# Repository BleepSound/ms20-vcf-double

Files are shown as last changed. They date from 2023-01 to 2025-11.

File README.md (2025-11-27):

[][cc-by-sa]

# Double MS20-VCF

Latest documentation available at https://bleepsound.github.io/modules/

This work is licensed under a
[Creative Commons Attribution-ShareAlike 4.0 International License][cc-by-sa].

[][cc-by-sa]

[cc-by-sa]: http://creativecommons.org/licenses/by-sa/4.0/
[cc-by-sa-image]: https://licensebuttons.net/l/by-sa/4.0/88x31.png
[cc-by-sa-shield]: https://img.shields.io/badge/License-CC%20BY--SA%204.0-lightgrey.svg

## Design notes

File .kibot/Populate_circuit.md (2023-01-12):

# Populate Manual for MS20-VCF-Double-circuitboard

Follow this manual to populate the PCB: 

The basic rule is, always go from the smallest to the highest component on the board !

- [[front | ]] This is the front side of the board we are populating
- [[back | ]] This is the back side of the board we are populating, and we are gonna start by this side.
- [[back | U1, U3 ]] Start by the SMD components, here U1 and U3, the LM13700s. 
- [[back | FB2, FB1]] After the smd components, do the beads.
- [[back | C7, C8, C11, C12 ]] Do all the ceramic capacitors
- [[back | C1, C5, C10, C15 ]] Finish the capacitors with the electrolytic ones, watch out for their orientation, they are polarized.
- [[back | J8, ResLv1, ResVol1, ResLv2, ResVol2 ]] Finish the back by putting the trimmers and the power connector.

The back is done, we can flip the PCB and start the front !

- [[front | ]]
- [[front | D1, D2, D3, D4, D5, D6, D8, D9, D10, D11, D12, D13 ]] First, populate all the diodes.
- [[front | R1, R2, R5, R6, R17, R23, R24, R27, R28, R39, R3, R4, R10, R11, R25, R26, R32, R33, R13, R14, R18, R35, R36, R40, R7, R9, R29, R31, R15, R37 ]] You then can do all the resistors (by value so you don't make mistakes)
- [[front | Q1, Q2, Q3, Q4 ]] You then can add the transitors, watch out for their orientation.
- [[front | U2, U4 ]] Add the socket for the TL072, making sure you get the orientation right. Don't add the Tl072 yet, you'll add it at the end. 
- [[front | C2, C3, C4, C16, C17, C18, C6, C9, C13, C14]] Add the capacitors

## Conclusion

This is the end of the build, if yoy have any questions, don't hesitate !

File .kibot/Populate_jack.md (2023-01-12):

# Populate Manual for MS20-VCF-Double-jackboard

Follow this manual to populate the PCB: 

The basic rule is, always go from the smallest to the highest component on the board !

- [[front | ]] This is the front side of the board we are populating (we'll start there)
- [[back | ]] This is the back side of the board we are populating (not much there on this build)
- [[front | R8, R12, R30, R34, R16, R38, R19, R41, R20, R42, R21, R43, R22 ]] We'll do all the resistors first (by value so you don't make mistakes)

We'll switch to the back:

- [[back | J4, J7, J10, J14 ]] just one type of components, the connectors to the circuit board. Use **Female** connectors on this side.

The last step  concern the jacks, potentiometers and switches and front panel LEDs. Basically, anything that is accessible throught the front panel. You first place them.

:warning: DO NOT SOLDER THEM YET :warning:

(this is really important !!)

- [[front | CUTCV1, CUTCV2, CUTOFF1, CUTOFF2, Res1, Res2, SW1, SW3, SW2, J1, J2, J5, J11, J12, J15, D7]] Do Not Solder Them! place them first and put the front panel in place. *For the pot **CUTCV1, CUTCV2**, use the small 100k pot (not D shaped)* The other pots are for CUTOFF1 and 2 and Res1 and 2. You'll be able to put the knobs of your choice on those. You can place the led too (D7). You'll have to place it as close as possible to the "window" on the front panel.

You then put in place the front panel, making sure everything fits. Once all the jack sockets and switches are fastenned to the front panel, you can solder them, and only then !!!

## Conclusion

This is the end of the build, if yoy have any questions, don't hesitate !

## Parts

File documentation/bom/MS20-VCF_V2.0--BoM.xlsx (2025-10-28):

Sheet: BoM
MS20-VCF_V2.0 Bill of Materials
Schematic: | MS20-VCF | Component Groups: | 23
Variant: | default | Component Count: | 109 (2 SMD/ 107 THT)
Revision: | 2.0 | Fitted Components: | 109 (2 SMD/ 107 THT)
Date: | 2025-10-19 | Number of PCBs: | 1
KiCad Version: | 9.0.4-9.0.4-0~ubuntu22.04.1 | Total Components: | 109
Row | Description | References | Value | Quantity Per PCB | Links | Comments
1 | Multilayer Monolithic Ceramic capacitor 50V 10% | C2 C3 C4 C16 C17 C18 | 1nF | 6 | https://www.taydaelectronics.com/capacitors/monolithic-ceramic-capacitor.html
2 | Multilayer Monolithic Ceramic capacitor 50V 10% | C6 C7 C8 C9 C11 C12 C13 C14 | 100nF | 8 | https://www.taydaelectronics.com/capacitors/monolithic-ceramic-capacitor.html
3 | 10uF Electrolytic capacitor, 2.0mm pitch, 5mm diameter | C1 C5 C10 C15 | 10uF | 4 | https://www.taydaelectronics.com/capacitors/electrolytic-capacitors.html
4 | Alpha/bourns vertical potentiometer | CUTCV1 CUTCV2 CUTOFF1 CUTOFF2 Res1 Res2 | B100k | 6 | https://www.thonk.co.uk/shop/alpha-9mm-pots/ | Use trimmer style pots for CUTCV1 and 2
5 | Switching Signal Diode 200mA 100V DO-35 | D1 D2 D3 D4 D5 D6 D8 D9 D10 D11 D12 D13 | 1N4148 | 12 | https://www.taydaelectronics.com/1n4148-switching-signal-diode.html
6 | 40V 1A Schottky Barrier Rectifier Diode, DO-41 | D7 D14 | 1N5819 (http://www.vishay.com/docs/88525/1n5817.pdf) | 2 | https://www.taydaelectronics.com/1n5819-schottky-barrier-diode-1a-40v.html
7 | 2.54mm pitch pin socket vertical 1x6pos | J3 J6 J9 J13 | Conn_CircuitBoard | 4
8 | 2.54mm pitch pin header vertical 1x6pos | J4 J7 J10 J14 | Conn_JackBoard | 4
9 | Eurorack 10 pin shrouded power header IDC | J8 | Power Input | 1 | https://www.thonk.co.uk/shop/eurorack-diy-essentials/
10 | Thonkiconn jack | J1 J2 J5 J11 J12 J15 | jack | 6 | https://www.thonk.co.uk/shop/thonkiconn/
11 | BC559 PNP General Purpose Transistor | Q1 Q2 Q3 Q4 | BC559 (https://www.onsemi.com/pub/Collateral/BC556BTA-D.pdf) | 4 | https://www.taydaelectronics.com/bc558-bc558b-transistor-pnp-0-1a-30v.html | Substitute BC558
12 | 2.5mm*6.8mm 1/4W 1% Metal film resistor | R3 R4 R10 R11 R25 R26 R32 R33 | 470 | 8 | https://www.taydaelectronics.com/resistors/1-4w-metal-film-resistors/test-group-2.html
13 | 2.5mm*6.8mm 1/4W 1% Metal film resistor | R8 R12 R15 R30 R34 R37 | 1k | 6 | https://www.taydaelectronics.com/resistors/1-4w-metal-film-resistors/test-group-2.html
14 | 2.5mm*6.8mm 1/4W 1% Metal film resistor | R7 R9 R29 R31 | 1.8k | 4 | https://www.taydaelectronics.com/resistors/1-4w-metal-film-resistors/test-group-2.html
15 | 2.5mm*6.8mm 1/4W 1% Metal film resistor | R13 R14 R18 R35 R36 R40 | 2.2k | 6 | https://www.taydaelectronics.com/resistors/1-4w-metal-film-resistors/test-group-2.html
16 | 2.5mm*6.8mm 1/4W 1% Metal film resistor | R19 R41 | 33k | 2 | https://www.taydaelectronics.com/resistors/1-4w-metal-film-resistors/test-group-2.html
17 | 2.5mm*6.8mm 1/4W 1% Metal film resistor | R21 R43 | 56k | 2 | https://www.taydaelectronics.com/resistors/1-4w-metal-film-resistors/test-group-2.html
18 | 2.5mm*6.8mm 1/4W 1% Metal film resistor | R16 R38 | 82k | 2 | https://www.taydaelectronics.com/resistors/1-4w-metal-film-resistors/test-group-2.html
19 | 2.5mm*6.8mm 1/4W 1% Metal film resistor | R1 R2 R5 R6 R17 R20 R23 R24 R27 R28 R39 R42 | 100k | 12 | https://www.taydaelectronics.com/resistors/1-4w-metal-film-resistors/test-group-2.html
20 | Trimmer potentiometer, 25 turn series 3296W | ResLv1 ResLv2 ResVol1 ResVol2 | 10k (https://www.taydaelectronics.com/potentiometer-variable-resistors/cermet-potentiometers/3296w/10k-ohm-trimmer-potentiometer-cermet-25-turns-3296w.html) | 4 | https://www.thonk.co.uk/shop/25-turn-trimmer-potentiometer/ | Use multi turn Cermet style 3296 pots
21 | Mini Toggle Switch DPDT On-On | SW1 SW3 | Hpass/Lpass Switch (https://www.taydaelectronics.com/mini-toggle-switch-1m-series-dpdt-on-on.html) | 2 | https://www.taydaelectronics.com/mini-toggle-switch-dpdt-on-on.html | DPDT Switch, On-Off-On
22 | Dual Transconductance Amplifiers | U1 U3 | LM13700 (http://www.ti.com/lit/ds/symlink/lm13700.pdf) | 2 | https://eu.mouser.com/c/semiconductors/amplifier-ics/transconductance-amplifiers/?series=LM13700
23 | Operational Amplifiers - Op Amps Dual JFET In Low N | U2 U4 | TL072 (http://www.ti.com/lit/ds/symlink/tl071.pdf) | 2 | https://eu.mouser.com/ProductDetail/Texas-Instruments/TL072IP?qs=5BZzbFV4k2v7IBrcArRPQw%3D%3D

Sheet: Colors
Columns colors
KiCad Fields (default)
Generated Fields
User Fields
Empty Fields

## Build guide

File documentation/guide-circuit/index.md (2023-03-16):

# Populate Manual for MS20-VCF-Double-circuitboard

Follow this manual to populate the PCB:

The basic rule is, always go from the smallest to the highest component on the board !

####  This is the front side of the board we are populating

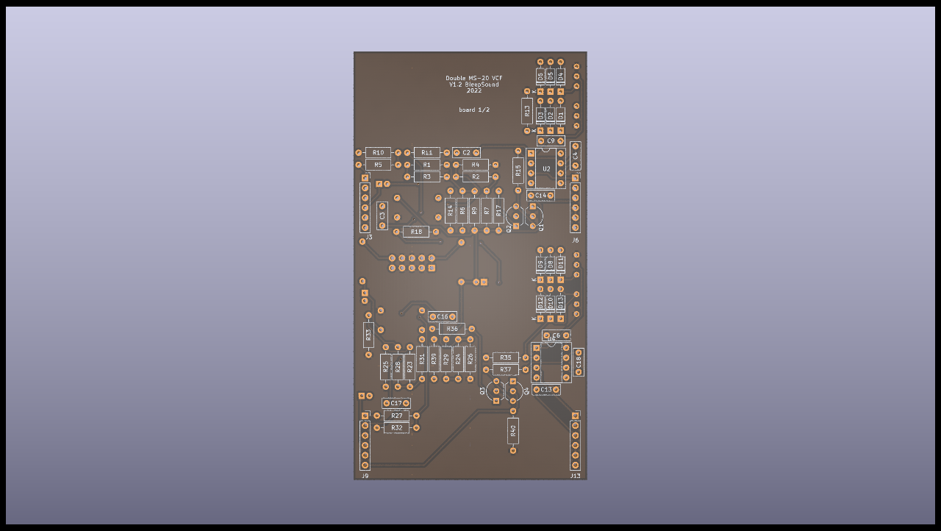
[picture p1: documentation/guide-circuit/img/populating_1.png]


####  This is the back side of the board we are populating, and we are gonna start by this side.

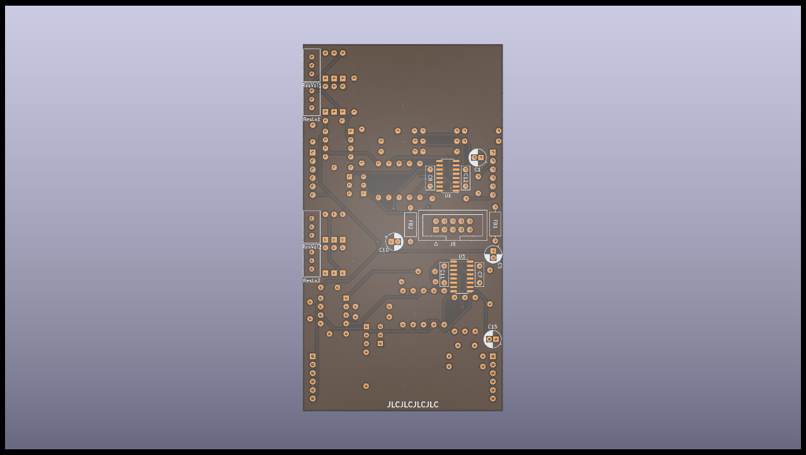
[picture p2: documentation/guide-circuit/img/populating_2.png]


####  Start by the SMD components, here U1 and U3, the LM13700s.

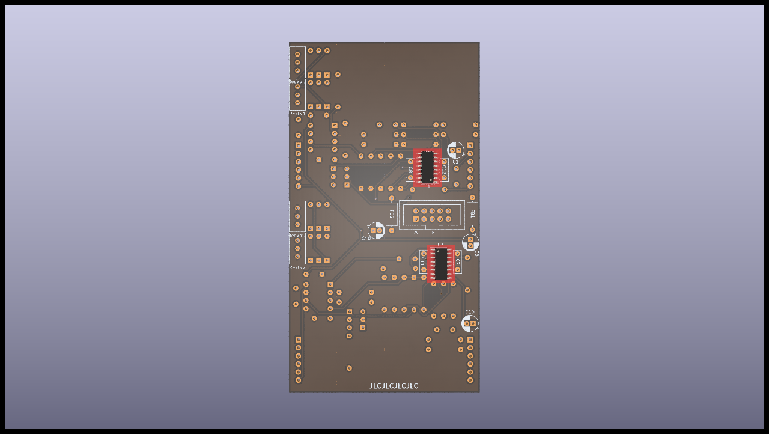
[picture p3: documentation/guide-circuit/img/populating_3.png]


####  After the smd components, do the beads.

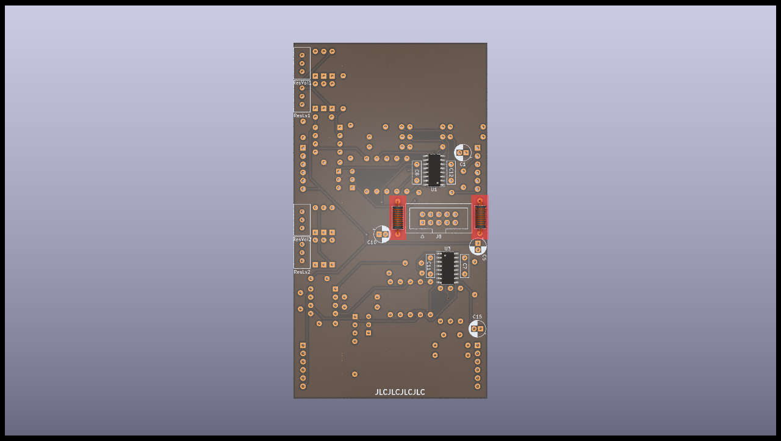
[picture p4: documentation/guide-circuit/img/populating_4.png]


####  Do all the ceramic capacitors

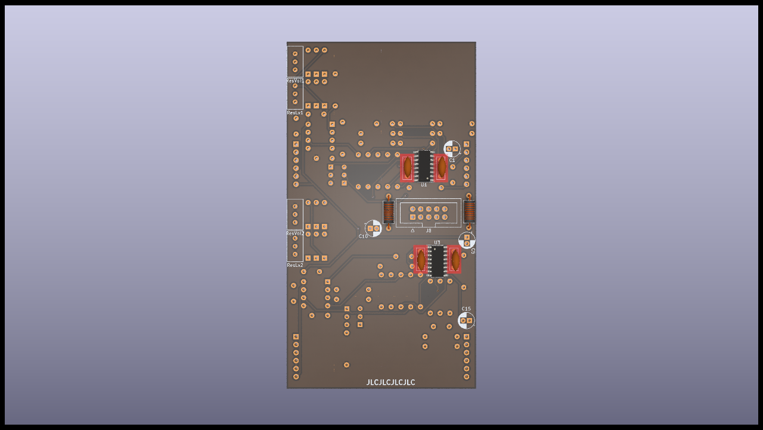
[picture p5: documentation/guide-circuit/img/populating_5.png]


####  Finish the capacitors with the electrolytic ones, watch out for their orientation, they are polarized.

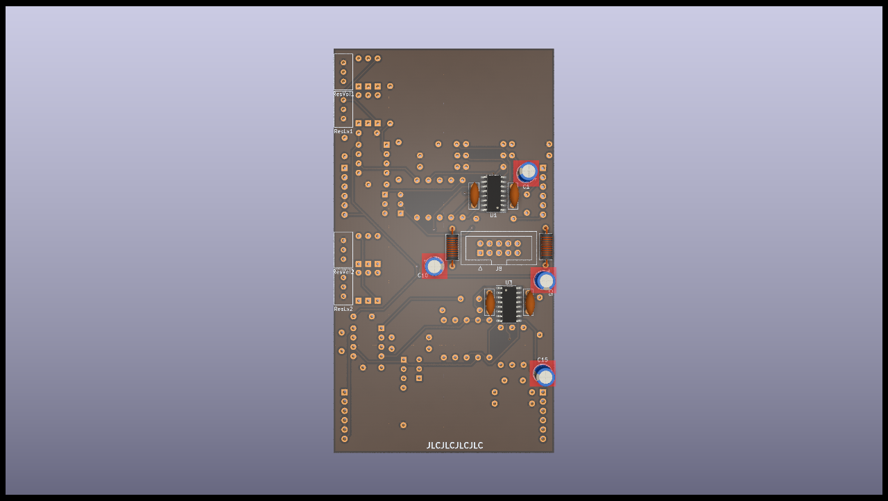
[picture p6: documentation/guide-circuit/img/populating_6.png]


####  Finish the back by putting the trimmers and the power connector.

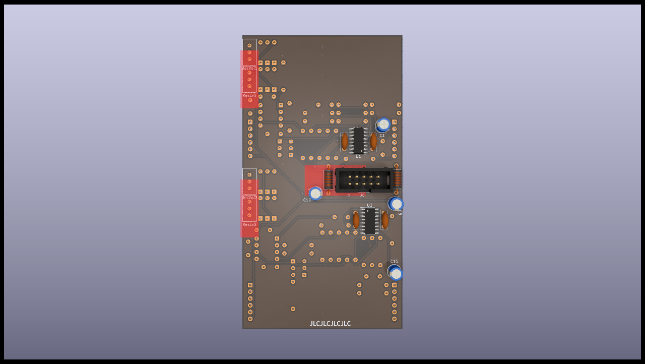
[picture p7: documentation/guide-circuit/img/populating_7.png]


The back is done, we can flip the PCB and start the front !

#### 

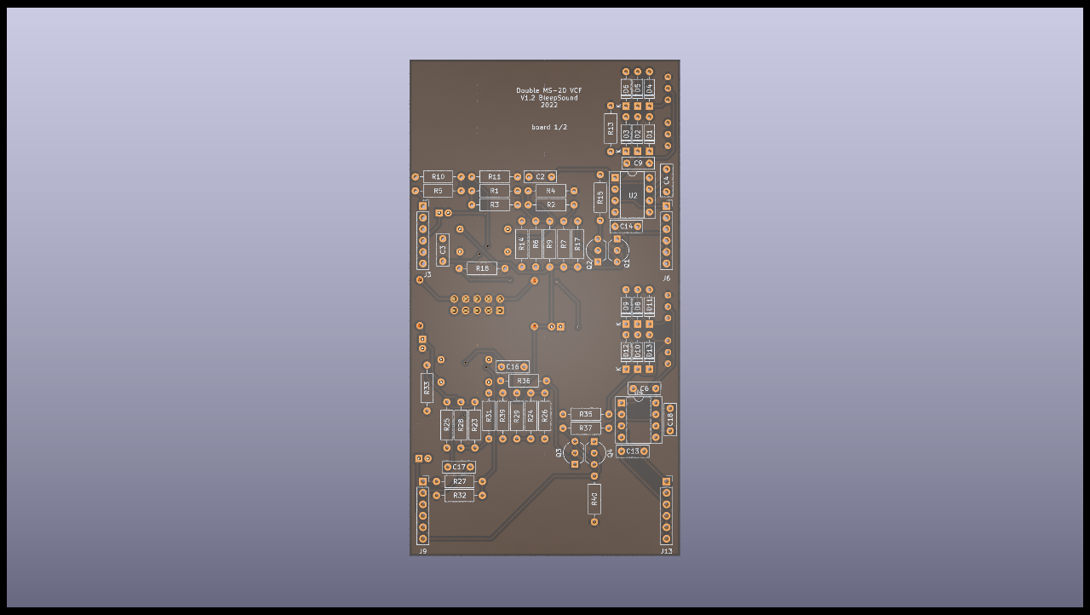
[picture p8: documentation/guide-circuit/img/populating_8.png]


####  First, populate all the diodes.

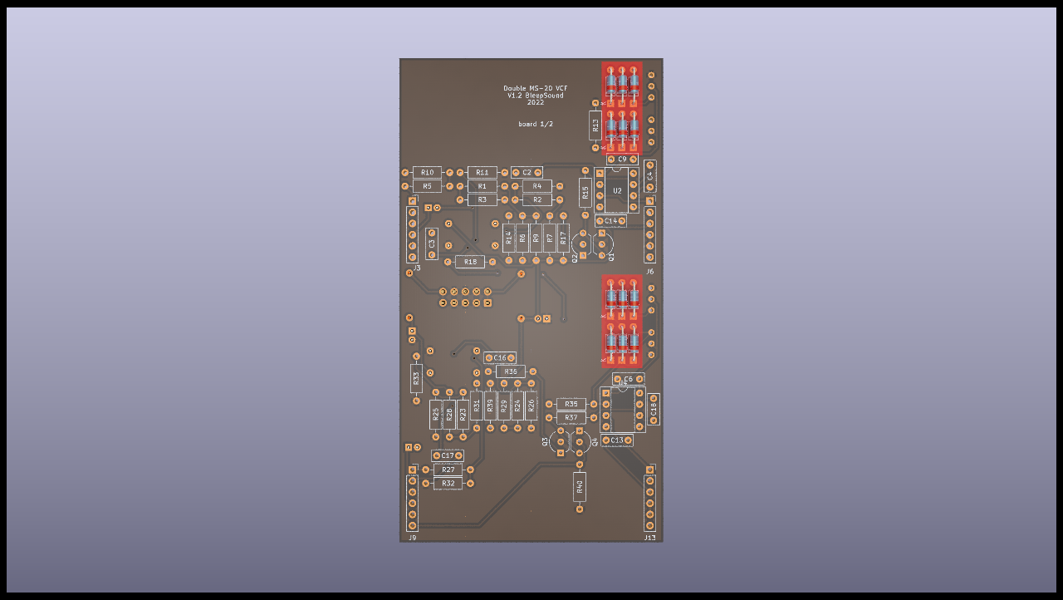
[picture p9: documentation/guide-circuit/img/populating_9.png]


####  You then can do all the resistors (by value so you don't make mistakes)

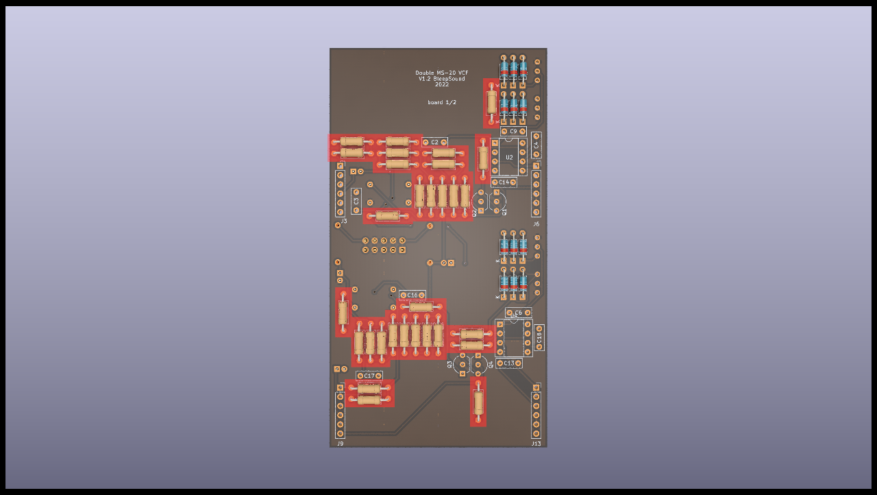
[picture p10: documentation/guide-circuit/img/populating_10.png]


####  You then can add the transitors, watch out for their orientation.

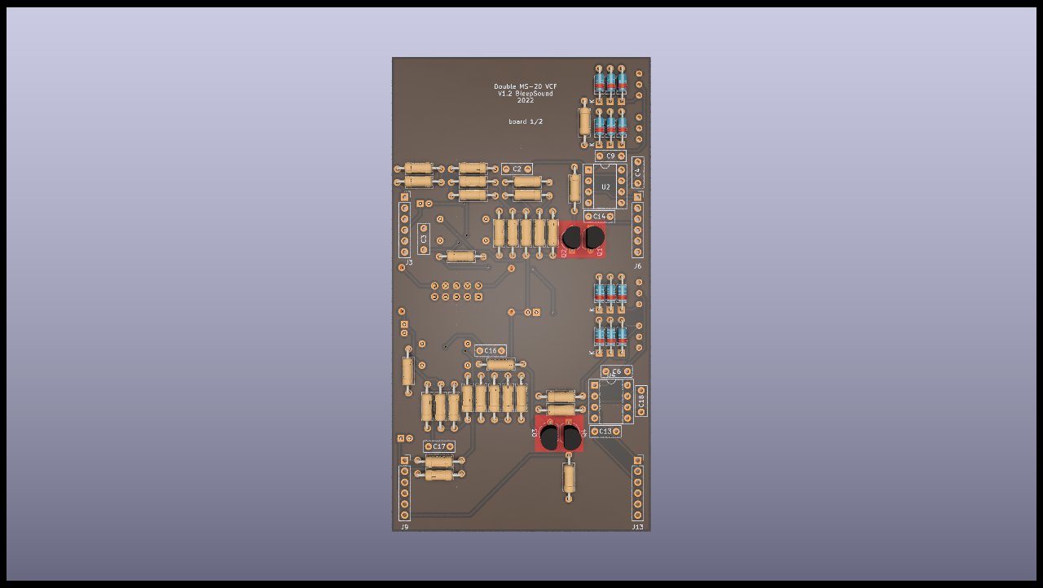
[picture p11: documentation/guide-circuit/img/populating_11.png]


####  Add the socket for the TL072, making sure you get the orientation right. Don't add the Tl072 yet, you'll add it at the end.

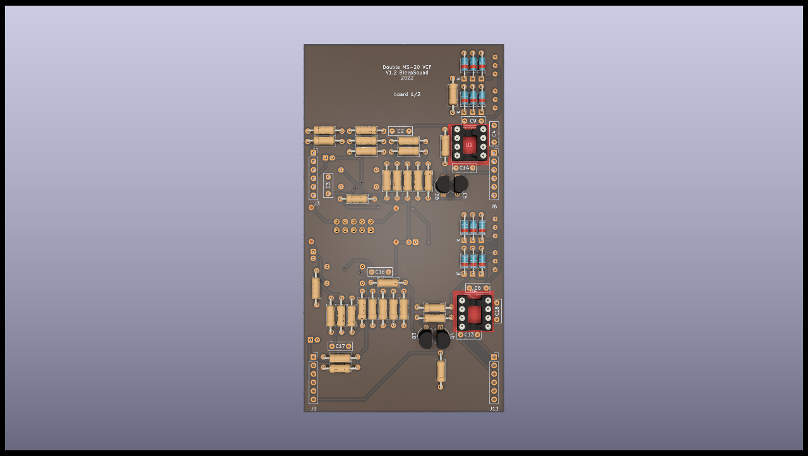
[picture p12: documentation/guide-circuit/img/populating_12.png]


####  Add the capacitors

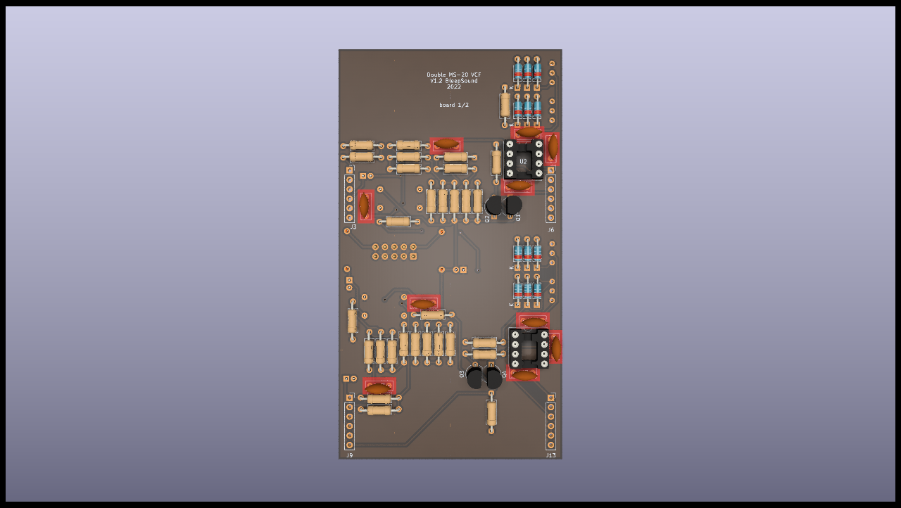
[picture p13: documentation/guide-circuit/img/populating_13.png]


## Conclusion

This is the end of the build, if yoy have any questions, don't hesitate !

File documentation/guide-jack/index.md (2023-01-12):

# Populate Manual for MS20-VCF-Double-jackboard

Follow this manual to populate the PCB: 

The basic rule is, always go from the smallest to the highest component on the board !

####  This is the front side of the board we are populating (we'll start there)

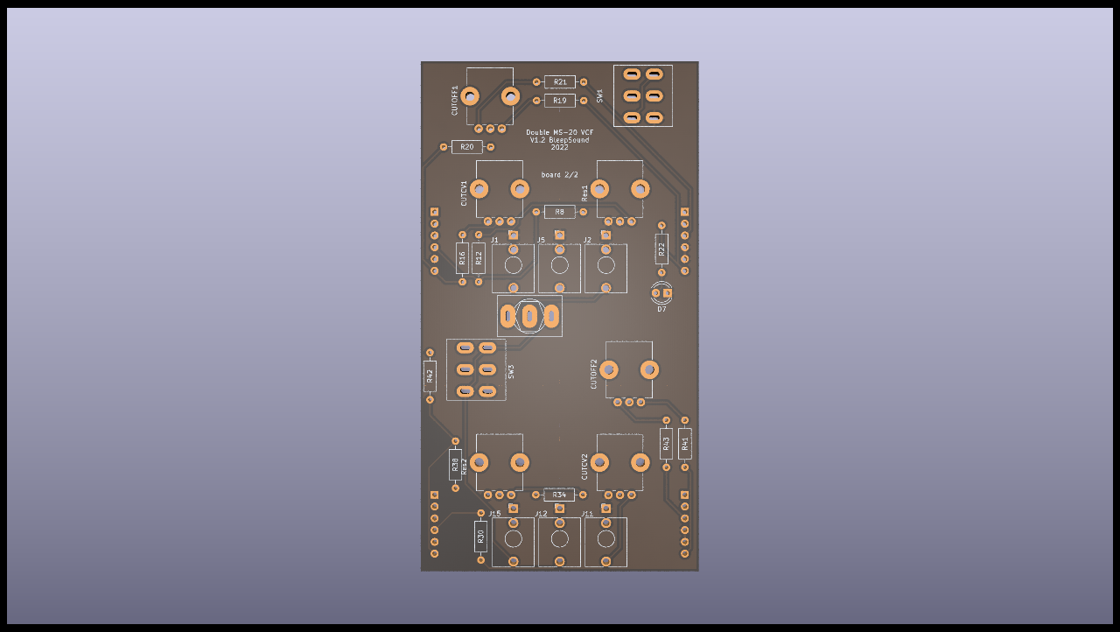
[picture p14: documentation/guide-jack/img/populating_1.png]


####  This is the back side of the board we are populating (not much there on this build)

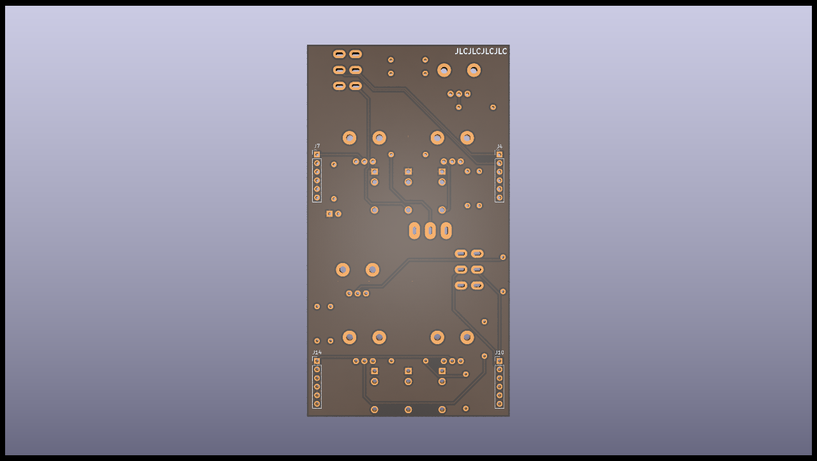
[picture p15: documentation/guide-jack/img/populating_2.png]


####  We'll do all the resistors first (by value so you don't make mistakes)

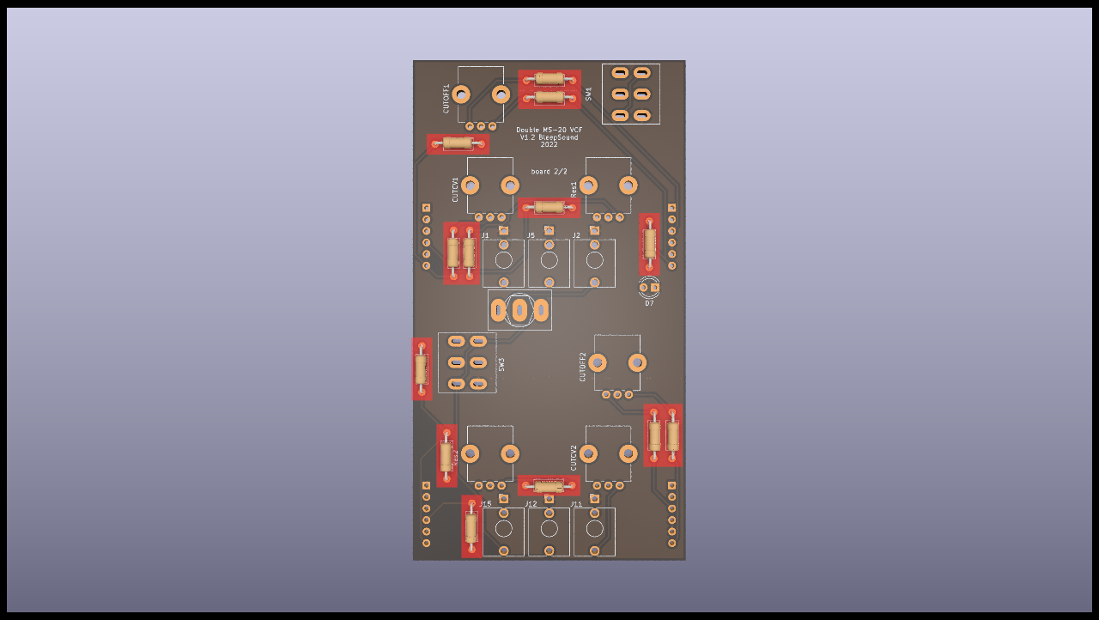
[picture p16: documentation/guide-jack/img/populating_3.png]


We'll switch to the back:

####  just one type of components, the connectors to the circuit board. Use __Female__  connectors on this side.

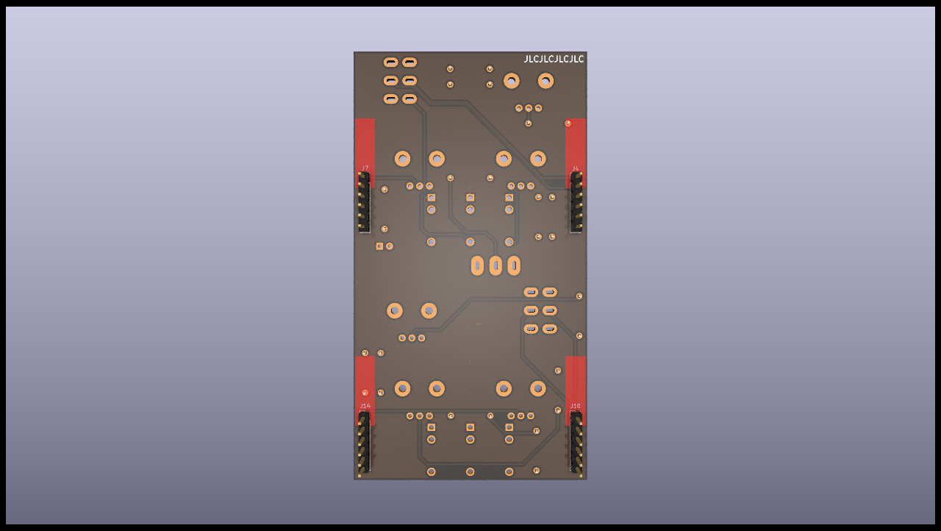
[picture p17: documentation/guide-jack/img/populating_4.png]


The last step  concern the jacks, potentiometers and switches and front panel LEDs. Basically, anything that is accessible throught the front panel. You first place them.

:warning: DO NOT SOLDER THEM YET :warning:

(this is really important !!)

####  Do Not Solder Them! place them first and put the front panel in place. _For the pot __CUTCV1, CUTCV2__ , use the small 100k pot (not D shaped)_  The other pots are for CUTOFF1 and 2 and Res1 and 2. You'll be able to put the knobs of your choice on those. You can place the led too (D7). You'll have to place it as close as possible to the "window" on the front panel.

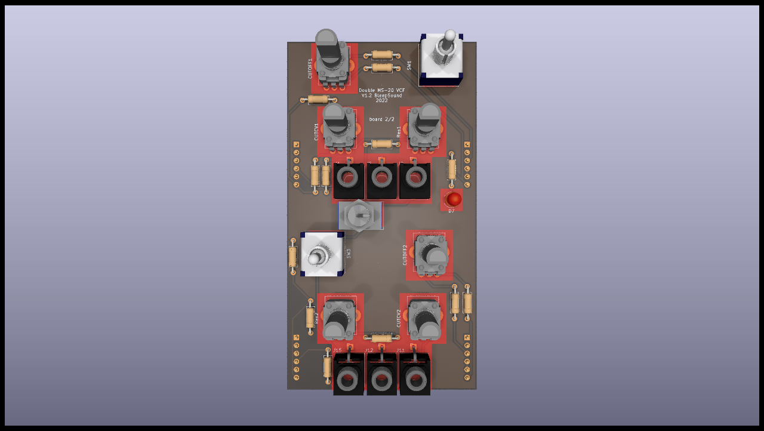
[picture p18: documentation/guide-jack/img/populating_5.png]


You then put in place the front panel, making sure everything fits. Once all the jack sockets and switches are fastenned to the front panel, you can solder them, and only then !!!

## Conclusion

This is the end of the build, if yoy have any questions, don't hesitate !

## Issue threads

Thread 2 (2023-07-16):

BOM question

Genmaizen, 2023-07-16:
Hi BleepSound,
Thank you very much for this project! I am planning to build this. As I am just a beginner in the DIY Eurorack hobby, I have some questions concerning the BOM:

- What parts exactly are FB1 and FB2?
- SW1 and SW3 are momentary switches – so push buttons – or just switches like SW2?
- D7 is a 4 mm LED? Currently I only knew 5 mm and 3 mm LEDs.

Thank´s and cheers,
Genmaizen

arthursaunier, 2023-09-01:
Hi!
Sorry for the late reply

- What parts exactly are FB1 and FB2?
They are ferrite beads, you can replace them by a straight wire if you want. (They're used to filter the power supply, they are not really mandatory).
- SW1 and SW3 are momentary switches i.e. push buttons. Or just switches like SW2?
SWI and SW3 are SPDT switches, not momentary switches, i'll switch the description in the bom. You can use this [model](https://www.taydaelectronics.com/mini-toggle-switch-1m-series-dpdt-on-on.html).
- D7 is a 4 mm LED. Is it ok to just take a 3 mm LED?
- Yup fine with a 3mm LED
Cheers

Genmaizen, 2023-09-02:
Thank you very much for the info! Looking forward to building the filter... 😊

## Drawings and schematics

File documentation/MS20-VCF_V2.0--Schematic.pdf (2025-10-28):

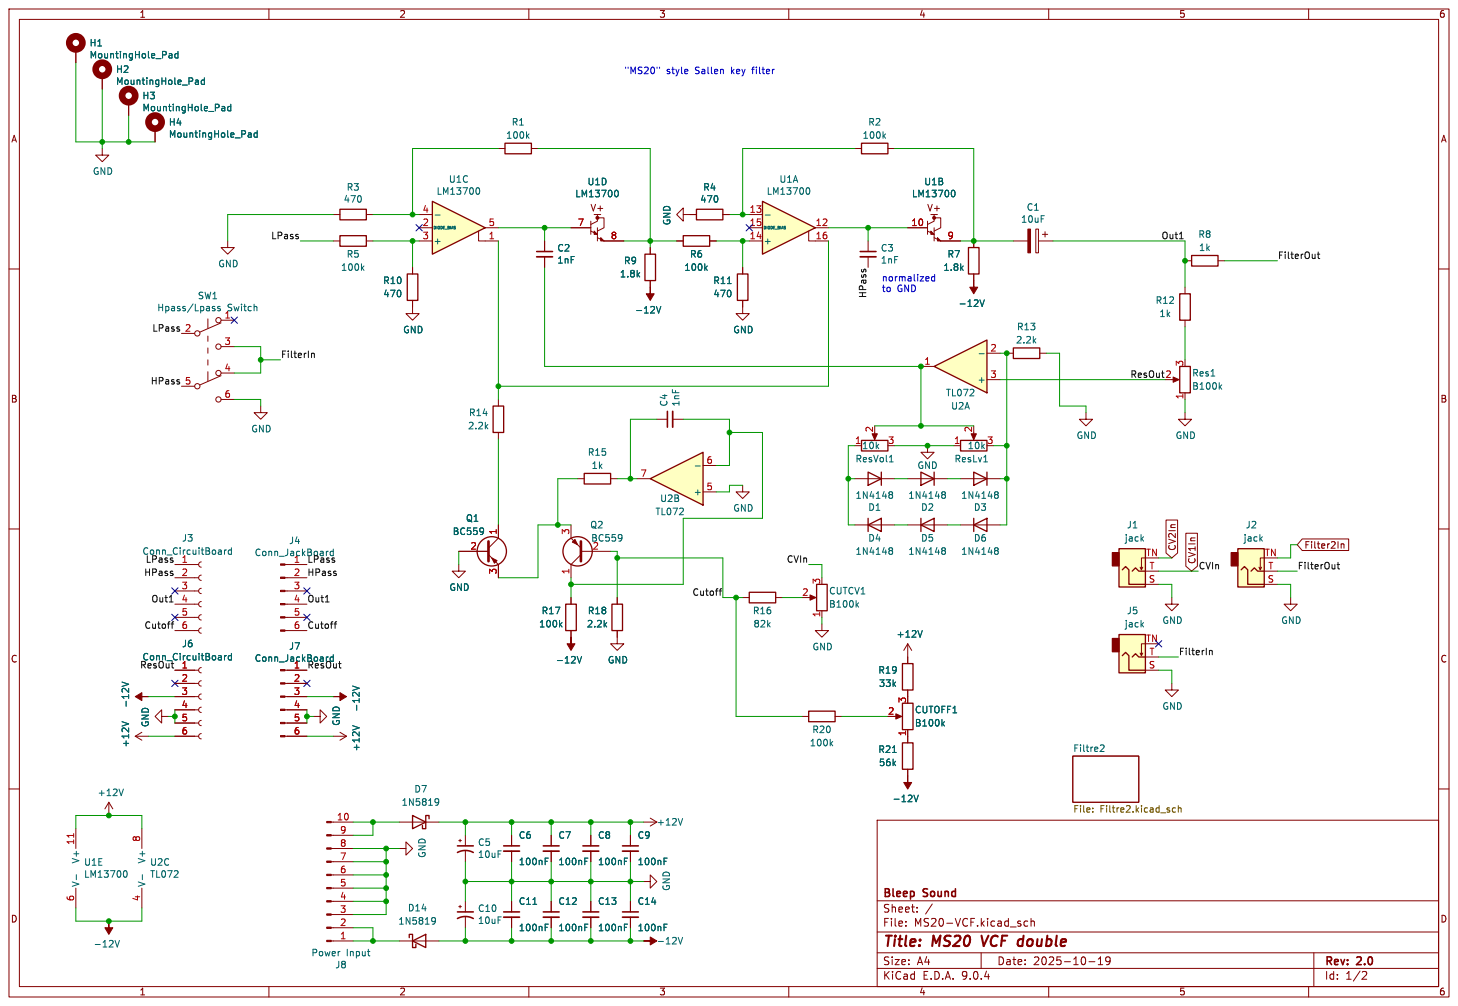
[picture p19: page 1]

Id: 1/2 Title: MS20 VCF double

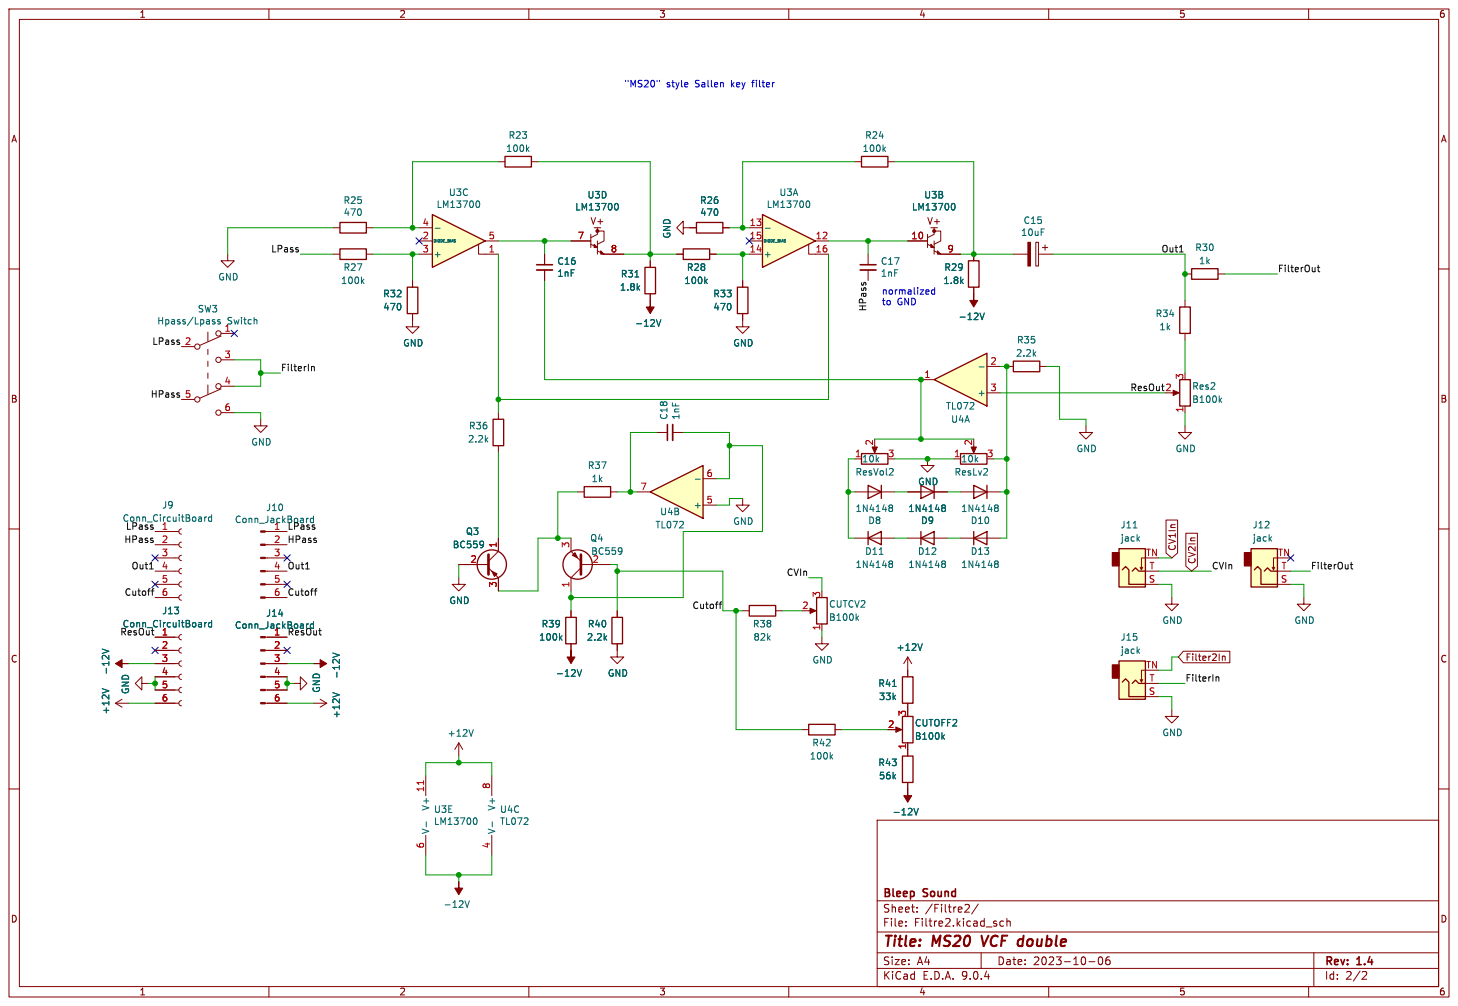
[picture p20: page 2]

Id: 2/2 Title: MS20 VCF double

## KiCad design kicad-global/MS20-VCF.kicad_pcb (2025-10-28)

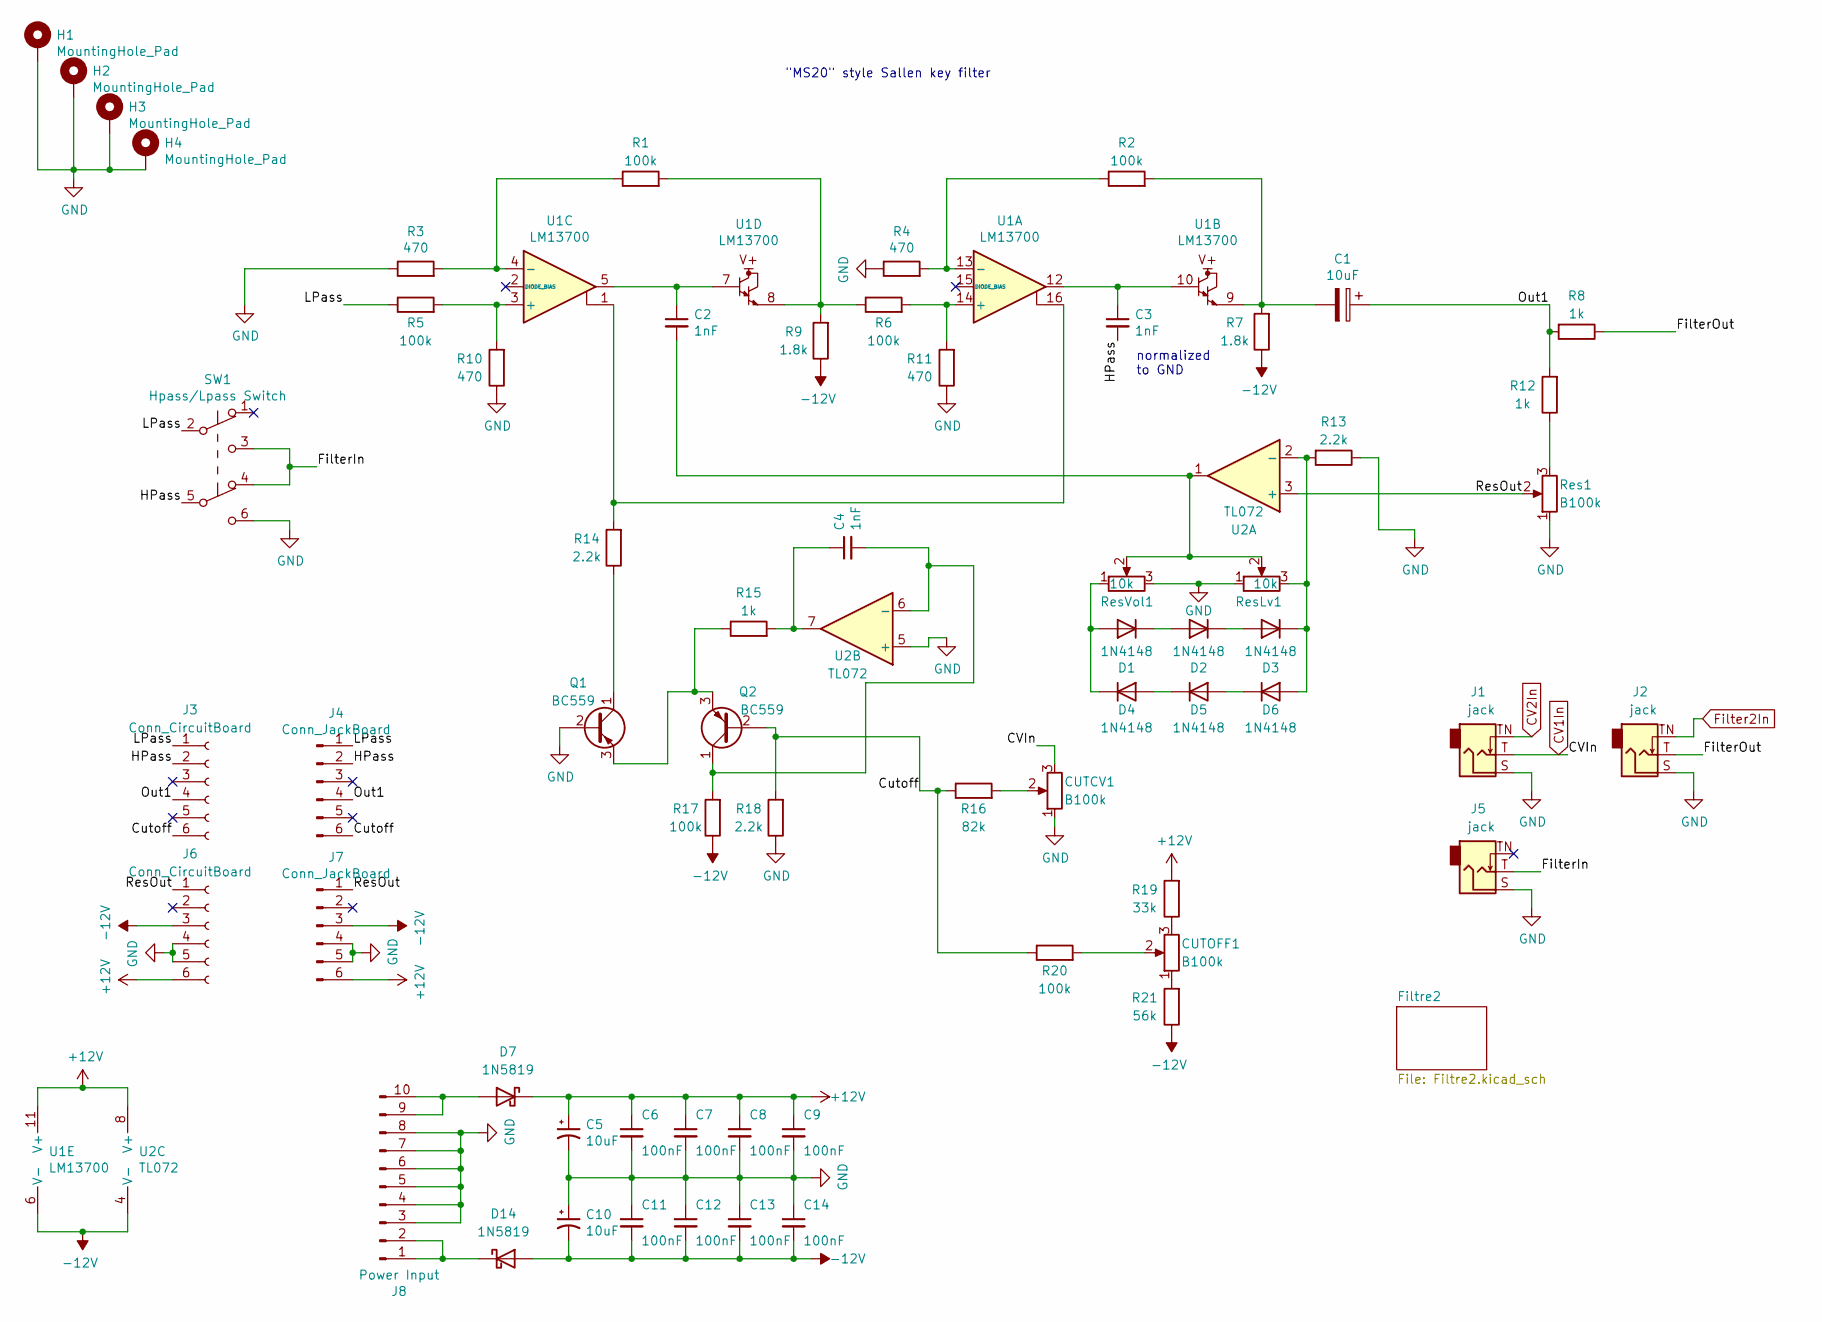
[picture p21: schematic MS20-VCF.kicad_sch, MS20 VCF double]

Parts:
C1, C5, C10: 10uF; CP_Radial_D5.0mm_P2.00mm
C2, C3, C4: 1nF; C_Disc_D7.0mm_W2.5mm_P5.00mm
C6, C7, C8, C9, C11, C12, C13, C14: 100nF; C_Disc_D7.0mm_W2.5mm_P5.00mm
CUTCV1: B100k; Pot-bourns-alpha
CUTOFF1: B100k; Pot-bourns-alpha
D1, D2, D3, D4, D5, D6: 1N4148; D_DO-35_SOD27_P7.62mm_Horizontal
D7, D14: 1N5819; D_DO-41_SOD81_P10.16mm_Horizontal
H1, H2, H3, H4: MountingHole_Pad; Doepfer Mounting hole
J1, J2, J5: jack; Thonkiconn
J3, J6: Conn_CircuitBoard; PinSocket_1x06_P2.54mm_Vertical
J4, J7: Conn_JackBoard; PinHeader_1x06_P2.54mm_Vertical
J8: Power Input; IDC-Header_2x05_P2.54mm_Vertical
Q1, Q2: BC559; TO-92_Inline_Wide
R1, R2, R5, R6, R17, R20: 100k; R_Axial_DIN0207_L6.3mm_D2.5mm_P10.16mm_Horizontal
R3, R4, R10, R11: 470; R_Axial_DIN0207_L6.3mm_D2.5mm_P10.16mm_Horizontal
R7, R9: 1.8k; R_Axial_DIN0207_L6.3mm_D2.5mm_P10.16mm_Horizontal
R8, R12, R15: 1k; R_Axial_DIN0207_L6.3mm_D2.5mm_P10.16mm_Horizontal
R13, R14, R18: 2.2k; R_Axial_DIN0207_L6.3mm_D2.5mm_P10.16mm_Horizontal
R16: 82k; R_Axial_DIN0207_L6.3mm_D2.5mm_P10.16mm_Horizontal
R19: 33k; R_Axial_DIN0207_L6.3mm_D2.5mm_P10.16mm_Horizontal
R21: 56k; R_Axial_DIN0207_L6.3mm_D2.5mm_P10.16mm_Horizontal
Res1: B100k; Pot-bourns-alpha
ResLv1: 10k; Potentiometer_Bourns_3296W_Vertical
ResVol1: 10k; Potentiometer_Bourns_3296W_Vertical
SW1: Hpass/Lpass Switch; SW_DPDT_Toggle
U1: LM13700; SOIC-16_3.9x9.9mm_P1.27mm
U2: TL072; DIP-8_W7.62mm_Socket

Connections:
+12V: C5.1, C6.1, C7.1, C8.1, C9.1, D7.1 (K), J6.6, J7.6, R19.2, U1.11 (V+), U2.8 (V+); also elsewhere on the board
-12V: C10.2, C11.2, C12.2, C13.2, C14.2, D14.2 (A), J6.3, J7.3, R7.1, R9.1, R17.1, R21.1, U1.6 (V-), U2.4 (V-); also elsewhere on the board
/Cutoff: J3.6, J4.6, Q2.2 (B), R16.1, R18.2, R20.1
/FilterIn: J5.T, SW1.3 (C), SW1.4 (A)
/FilterOut: J2.T, R8.1
/HPass: C3.2, J3.2, J4.2, SW1.5 (B)
/LPass: J3.1, J4.1, R5.1, SW1.2 (B)
/Out1: C1.1, J3.4, J4.4, R8.2, R12.2
/ResOut: J6.1, J7.1, Res1.2, U2.3 (+)
CV1In: CUTCV1.3, J1.T; also elsewhere on the board
CV2In: J1.TN; also elsewhere on the board
Filter2In: J2.TN; also elsewhere on the board
GND: C5.2, C6.2, C7.2, C8.2, C9.2, C10.1, C11.1, C12.1, C13.1, C14.1, CUTCV1.1, H1.1, H2.1, H3.1, H4.1, J1.S, J2.S, J5.S, J6.4, J6.5, J7.4, J7.5, J8.3, J8.4, J8.5, J8.6, J8.7, J8.8, Q1.2 (B), R3.1, R4.1, R10.1, R11.1, R13.1, R18.1, Res1.1, ResLv1.1, ResVol1.3, SW1.6 (C), U2.5 (+); also elsewhere on the board
unnamed: C1.2, R2.2, R7.2, U1.9
unnamed: C2.1, U1.5, U1.7
unnamed: C2.2, ResLv1.2, ResVol1.2, U2.1
unnamed: C3.1, U1.10, U1.12
unnamed: C4.1, R15.2, U2.7
unnamed: CUTCV1.2, R16.2
unnamed: CUTOFF1.1, R21.2
unnamed: CUTOFF1.2, R20.2
unnamed: CUTOFF1.3, R19.1
unnamed: D1.2 (A), D4.1 (K), ResVol1.1
unnamed: D1.1 (K), D2.2 (A)
unnamed: D2.1 (K), D3.2 (A)
unnamed: D3.1 (K), D6.2 (A), R13.2, ResLv1.3, U2.2 (-)
unnamed: D4.2 (A), D5.1 (K)
unnamed: D5.2 (A), D6.1 (K)
unnamed: D7.2 (A), J8.9, J8.10
unnamed: D14.1 (K), J8.1, J8.2
unnamed: Q1.1 (C), R14.1
unnamed: Q1.3 (E), Q2.3 (E), R15.1
unnamed: C4.2, Q2.1 (C), R17.2, U2.6 (-)
unnamed: R1.2, R6.1, R9.2, U1.8
unnamed: R12.1, Res1.3
unnamed: R14.2, U1.1, U1.16
unnamed: R6.2, R11.2, U1.14 (+)
unnamed: R2.1, R4.2, U1.13 (-)
unnamed: R5.2, R10.2, U1.3 (+)
unnamed: R1.1, R3.2, U1.4 (-)

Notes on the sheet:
normalized to GND
"MS20" style Sallen key filter

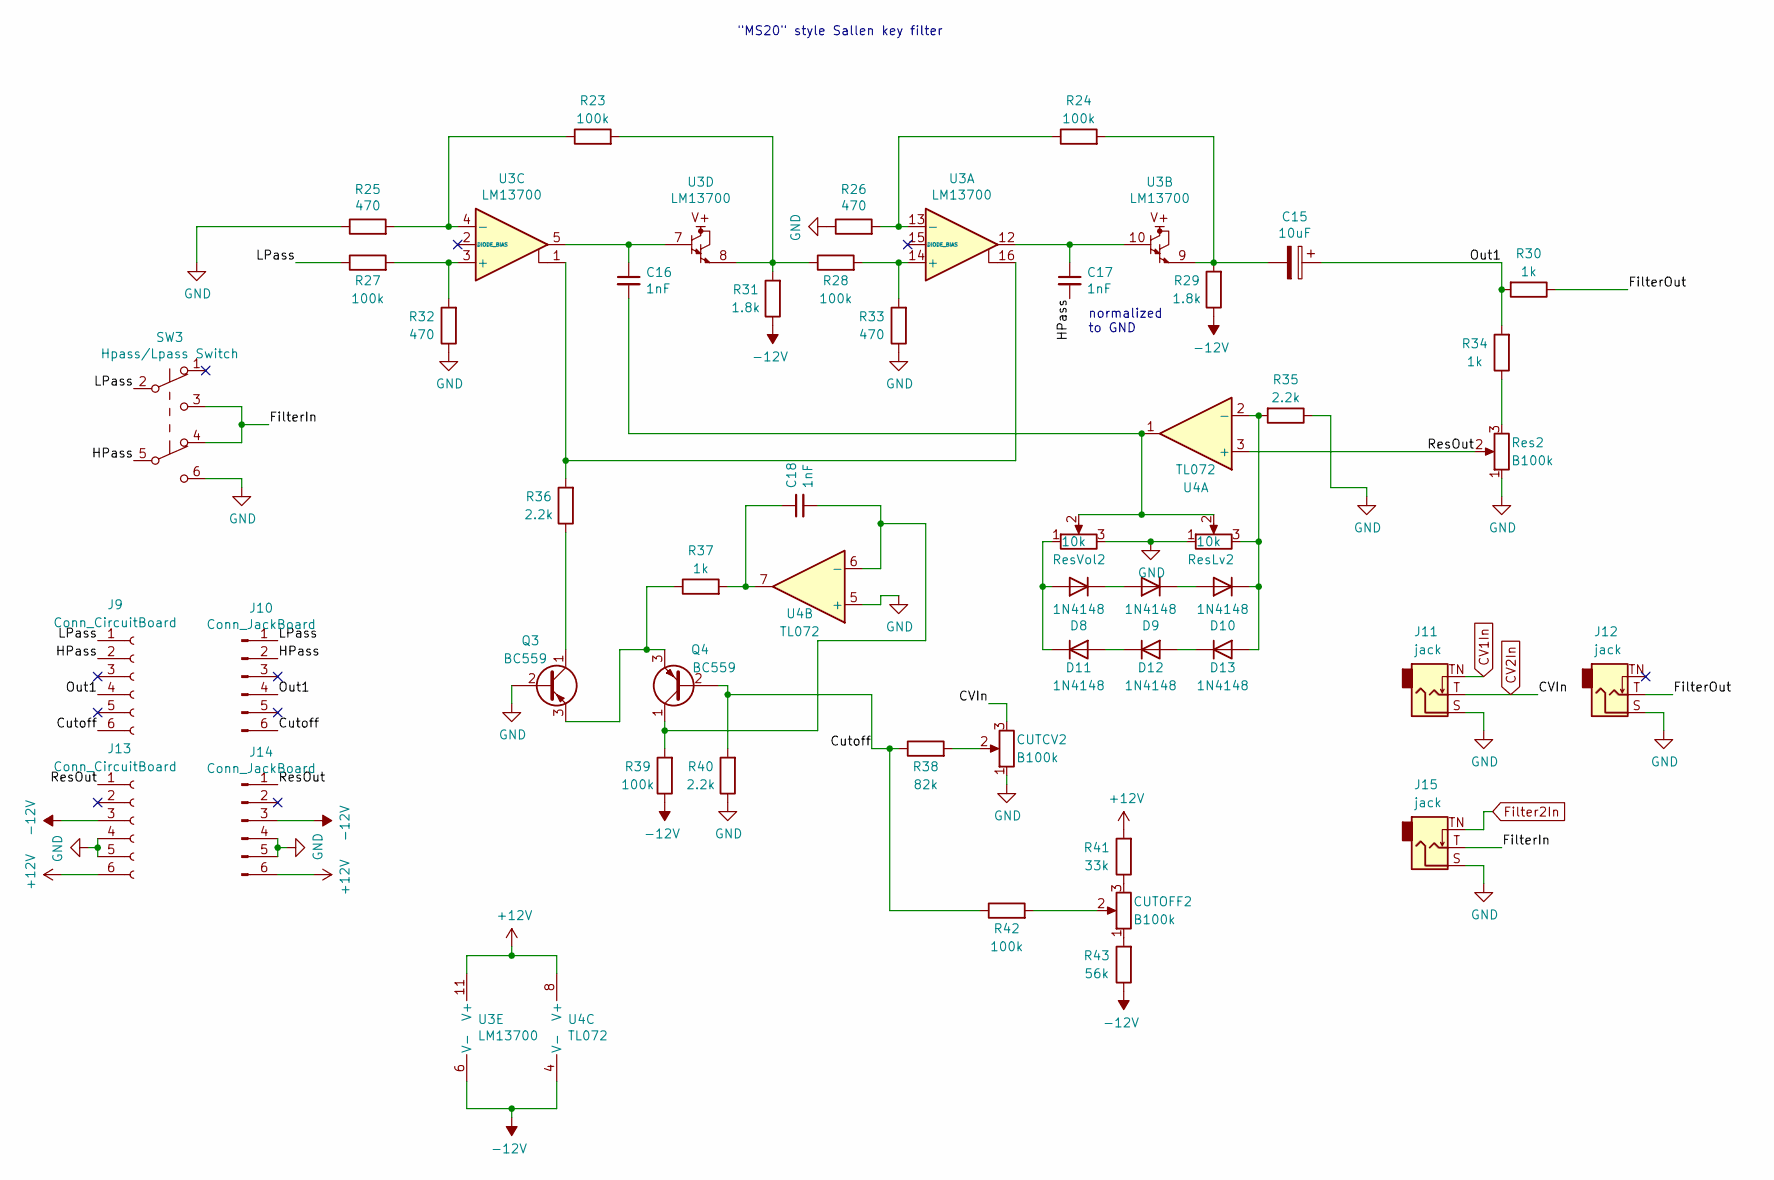
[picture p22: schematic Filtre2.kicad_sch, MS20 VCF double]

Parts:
C15: 10uF; CP_Radial_D5.0mm_P2.00mm
C16, C17, C18: 1nF; C_Disc_D7.0mm_W2.5mm_P5.00mm
CUTCV2: B100k; Pot-bourns-alpha
CUTOFF2: B100k; Pot-bourns-alpha
D8, D9, D10, D11, D12, D13: 1N4148; D_DO-35_SOD27_P7.62mm_Horizontal
J9, J13: Conn_CircuitBoard; PinSocket_1x06_P2.54mm_Vertical
J10, J14: Conn_JackBoard; PinHeader_1x06_P2.54mm_Vertical
J11, J12, J15: jack; Thonkiconn
Q3, Q4: BC559; TO-92_Inline_Wide
R23, R24, R27, R28, R39, R42: 100k; R_Axial_DIN0207_L6.3mm_D2.5mm_P10.16mm_Horizontal
R25, R26, R32, R33: 470; R_Axial_DIN0207_L6.3mm_D2.5mm_P10.16mm_Horizontal
R29, R31: 1.8k; R_Axial_DIN0207_L6.3mm_D2.5mm_P10.16mm_Horizontal
R30, R34, R37: 1k; R_Axial_DIN0207_L6.3mm_D2.5mm_P10.16mm_Horizontal
R35, R36, R40: 2.2k; R_Axial_DIN0207_L6.3mm_D2.5mm_P10.16mm_Horizontal
R38: 82k; R_Axial_DIN0207_L6.3mm_D2.5mm_P10.16mm_Horizontal
R41: 33k; R_Axial_DIN0207_L6.3mm_D2.5mm_P10.16mm_Horizontal
R43: 56k; R_Axial_DIN0207_L6.3mm_D2.5mm_P10.16mm_Horizontal
Res2: B100k; Pot-bourns-alpha
ResLv2: 10k; Potentiometer_Bourns_3296W_Vertical
ResVol2: 10k; Potentiometer_Bourns_3296W_Vertical
SW3: Hpass/Lpass Switch; SW_DPDT_Toggle
U3: LM13700; SOIC-16_3.9x9.9mm_P1.27mm
U4: TL072; DIP-8_W7.62mm_Socket

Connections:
+12V: J13.6, J14.6, R41.2, U3.11 (V+), U4.8 (V+); also elsewhere on the board
-12V: J13.3, J14.3, R29.1, R31.1, R39.1, R43.1, U3.6 (V-), U4.4 (V-); also elsewhere on the board
/Filtre2/Cutoff: J9.6, J10.6, Q4.2 (B), R38.1, R40.2, R42.1
/Filtre2/FilterIn: J15.T, SW3.3 (C), SW3.4 (A)
/Filtre2/FilterOut: J12.T, R30.1
/Filtre2/HPass: C17.2, J9.2, J10.2, SW3.5 (B)
/Filtre2/LPass: J9.1, J10.1, R27.1, SW3.2 (B)
/Filtre2/Out1: C15.1, J9.4, J10.4, R30.2, R34.2
/Filtre2/ResOut: J13.1, J14.1, Res2.2, U4.3 (+)
CV1In: J11.TN; also elsewhere on the board
CV2In: CUTCV2.3, J11.T; also elsewhere on the board
Filter2In: J15.TN; also elsewhere on the board
GND: CUTCV2.1, J11.S, J12.S, J13.4, J13.5, J14.4, J14.5, J15.S, Q3.2 (B), R25.1, R26.1, R32.1, R33.1, R35.1, R40.1, Res2.1, ResLv2.1, ResVol2.3, SW3.6 (C), U4.5 (+); also elsewhere on the board
unnamed: C15.2, R24.2, R29.2, U3.9
unnamed: C16.1, U3.5, U3.7
unnamed: C16.2, ResLv2.2, ResVol2.2, U4.1
unnamed: C17.1, U3.10, U3.12
unnamed: C18.1, R37.2, U4.7
unnamed: CUTCV2.2, R38.2
unnamed: CUTOFF2.1, R43.2
unnamed: CUTOFF2.2, R42.2
unnamed: CUTOFF2.3, R41.1
unnamed: D8.1 (K), D9.2 (A)
unnamed: D9.1 (K), D10.2 (A)
unnamed: D10.1 (K), D13.2 (A), R35.2, ResLv2.3, U4.2 (-)
unnamed: D11.2 (A), D12.1 (K)
unnamed: D8.2 (A), D11.1 (K), ResVol2.1
unnamed: D12.2 (A), D13.1 (K)
unnamed: Q3.1 (C), R36.1
unnamed: Q3.3 (E), Q4.3 (E), R37.1
unnamed: C18.2, Q4.1 (C), R39.2, U4.6 (-)
unnamed: R23.2, R28.1, R31.2, U3.8
unnamed: R34.1, Res2.3
unnamed: R36.2, U3.1, U3.16
unnamed: R28.2, R33.2, U3.14 (+)
unnamed: R24.1, R26.2, U3.13 (-)
unnamed: R27.2, R32.2, U3.3 (+)
unnamed: R23.1, R25.2, U3.4 (-)

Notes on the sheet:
normalized to GND
"MS20" style Sallen key filter

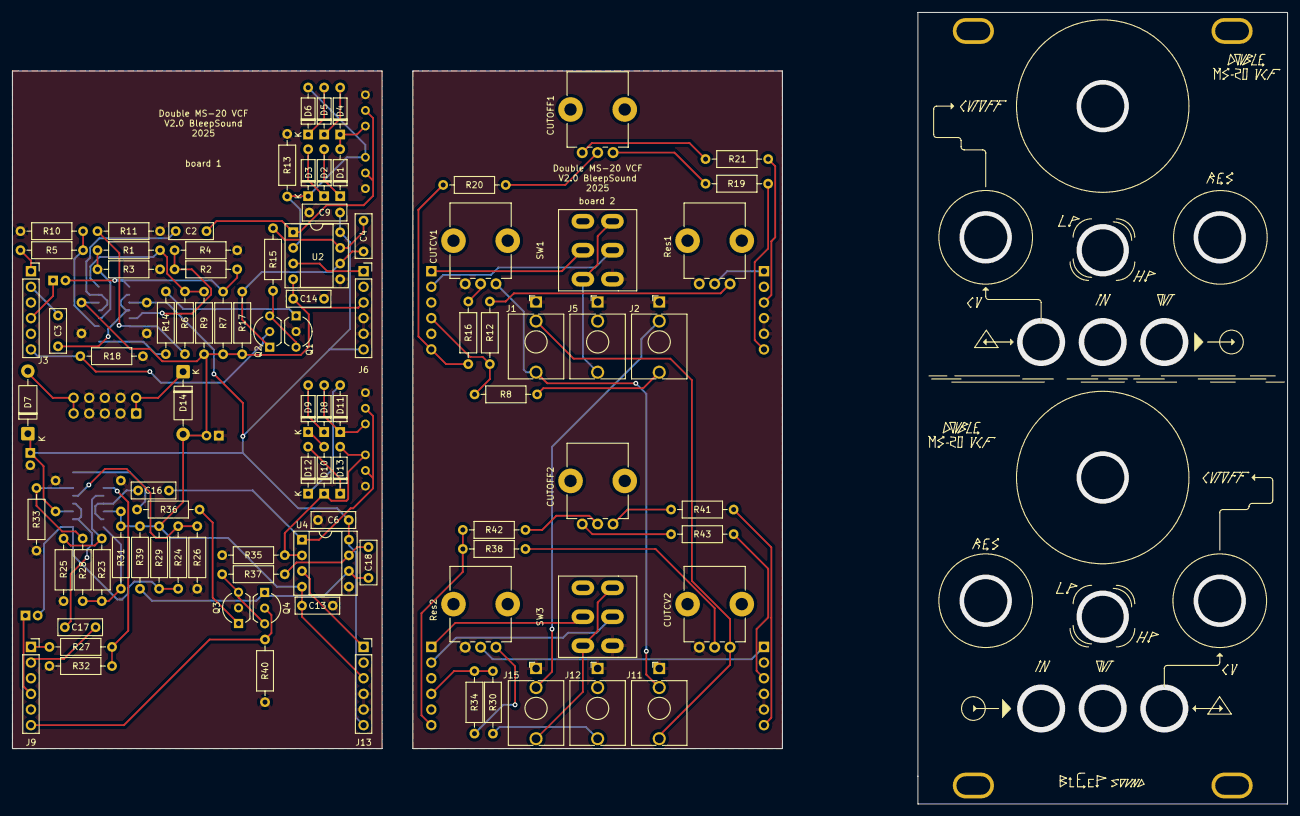
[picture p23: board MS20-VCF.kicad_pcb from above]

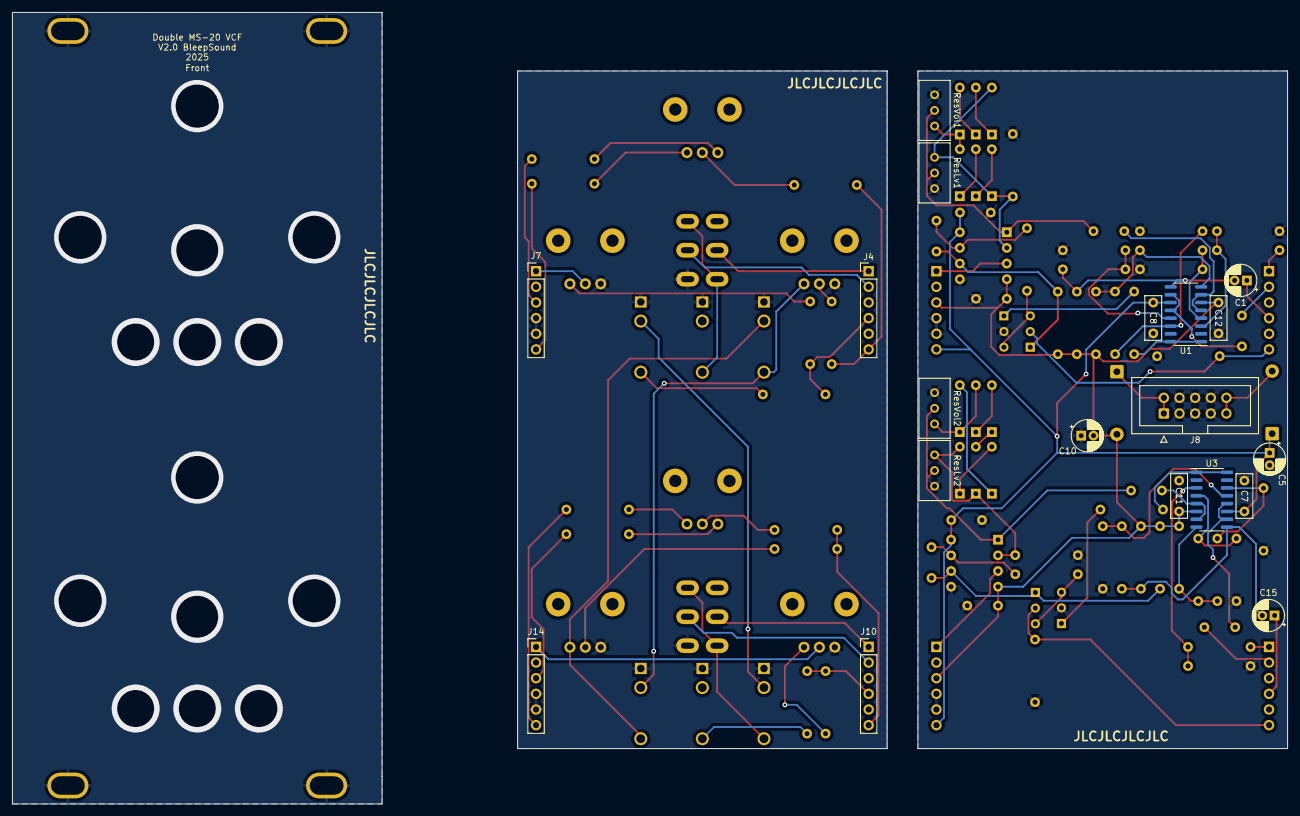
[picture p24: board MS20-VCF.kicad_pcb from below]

Board: 2 copper layers, 207.0 x 128.5 mm, 113 parts (19 on the bottom side), 72 nets.

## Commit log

2023-01-12 initial commit with all files and workflows updated
    [Filtre2.kicad_sch, MS20-VCF.kicad_pcb, MS20-VCF.kicad_sch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]
2023-01-12 add circuit BoM
2023-01-12 add front gerber
    [MS20-VCF--NPTH_map.gbr, MS20-VCF--PTH_map.gbr, MS20-VCF-B_Cu.gbl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]
2023-01-12 add main BoM and images
    [MS20-VCF-bom.xlsx]
2023-01-12 add jack BoM
2023-01-12 add jack gerber
    [MS20-VCF--NPTH_map.gbr, MS20-VCF--PTH_map.gbr, MS20-VCF-B_Cu.gbl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]
2023-01-12 fix issues and add guide
    [Filtre2.kicad_sch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]
2023-01-12 add circuit gerber
    [MS20-VCF--NPTH_map.gbr, MS20-VCF--PTH_map.gbr, MS20-VCF-B_Cu.gbl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]
2023-01-20 update bom file
2023-02-18 update worflow run condition + trimmer footprint update
    [Filtre2.kicad_sch, MS20-VCF.kicad_pcb, MS20-VCF.kicad_sch]
2023-03-16 update value for trimmer
    [Filtre2.kicad_sch, MS20-VCF.kicad_sch]
2023-06-10 update front panel and infos on components
    [Filtre2.kicad_sch, MS20-VCF.kicad_pcb, MS20-VCF.kicad_sch]
2023-06-10 fix issue with kibot to use kicad 7
2023-09-23 update documentation + update repo layout
    [Filtre2.kicad_sch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]
2023-10-15 update version number + hole size on front panel
    [Filtre2.kicad_sch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]
2023-12-10 add extra info for bom
2024-10-19 add link to download BOM in Excel
2025-10-28 V2.0
    new front panel layout
    new normalisation for CV and in/out for bandpass filter
    [Filtre2.kicad_sch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]

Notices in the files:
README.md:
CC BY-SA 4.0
